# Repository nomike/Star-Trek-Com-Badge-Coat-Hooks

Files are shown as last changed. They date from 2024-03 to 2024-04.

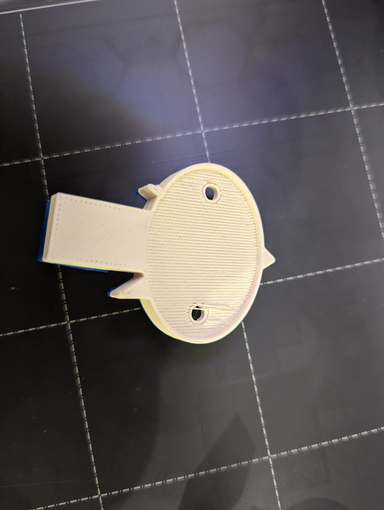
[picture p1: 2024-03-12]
photos/backside.png

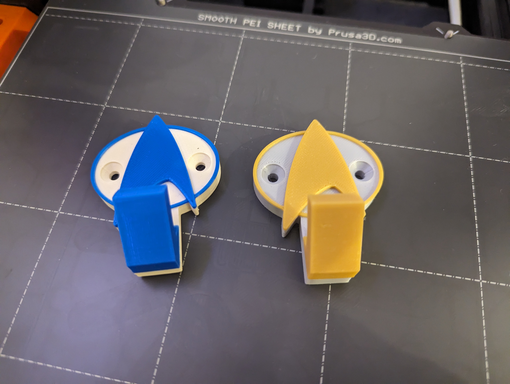
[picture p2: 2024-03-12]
photos/hooks.png

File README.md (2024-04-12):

Coat hooks featuring a Star Trek communicator badge. The hooks are designed to be mounted to a wall and are perfect for hanging coats, hats, or anything else you can think of.

#### Acknowledgements

Uses the follwing projects:

* <https://github.com/lar3ry/OpenSCAD---Move-STL-to-origin/tree/master> - To move the imported STL to the origin.
* <https://www.thingiverse.com/thing:1731893> - An OpenSCAD library for creating screw holes
* <https://worldvectorlogo.com/logo/starfleet> - for the Starfleet logo - Original design most likely owned by CBS - Edited with Inkscape into `star_fleet.svg`.
* <https://www.thingiverse.com/thing:49> - Coat Hook

#### Design

The back of the hook is hollowed out to account for uneven walls or dowels wich are not completely flush. This requires supports, but as they are attached to an invisible part of the hook, they don't influence the final appearance at all.

#### Colors

As you can see, introducing a filament change at the right layer provides for a very nice visual effect.

#### Knob

If you change the parameter `type` to `knob` you can print a knob instead of a hook. This is useful if you want to use the badge as a drawer knob or something similar. I haven't printed this version yet though.

#### Thingiverse

<https://www.thingiverse.com/thing:6528411>

#### GitHub

<https://github.com/nomike/star-trek-com-badge-coat-hook-and-door-knob>

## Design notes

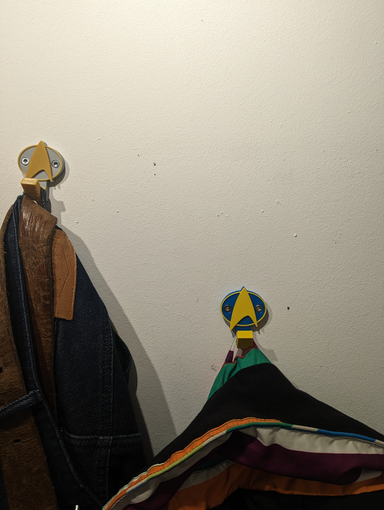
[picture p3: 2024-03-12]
photos/mounted.png

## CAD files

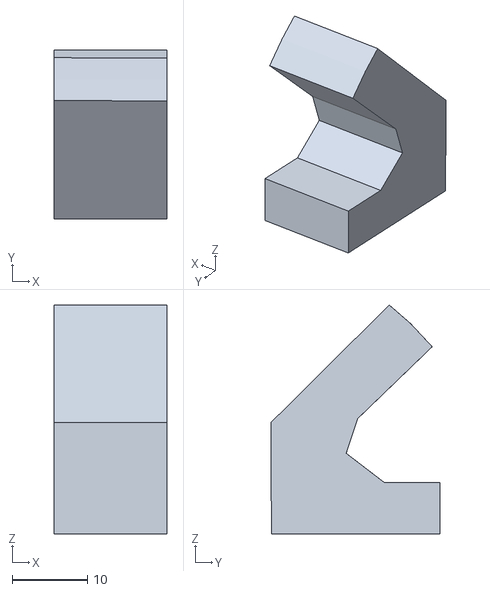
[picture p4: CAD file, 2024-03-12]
hook.stl
15.0 x 22.5 x 30.4

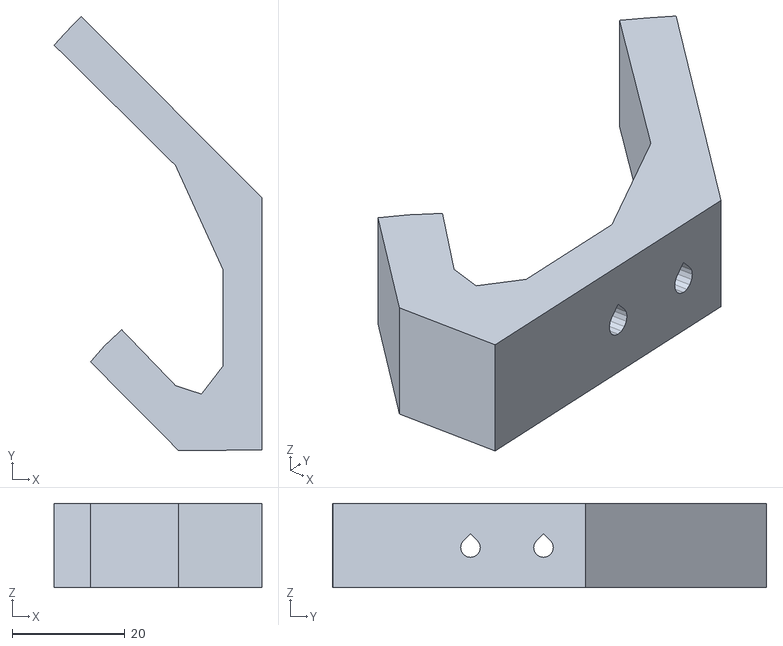
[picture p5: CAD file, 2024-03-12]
Coat-hook.stl
36.9 x 77.1 x 15.0

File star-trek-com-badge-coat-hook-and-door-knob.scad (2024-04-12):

/*
Star Trek Com Badge Coat Hooks

Copyright 2024 nomike[AT]nomike[DOT]com

Redistribution and use in source and binary forms, with or without
modification, are permitted provided that the following conditions are met:

1. Redistributions of source code must retain the above copyright notice, this
list of conditions and the following disclaimer.

2. Redistributions in binary form must reproduce the above copyright notice,
this list of conditions and the following disclaimer in the documentation
and/or other materials provided with the distribution.

THIS SOFTWARE IS PROVIDED BY THE COPYRIGHT HOLDERS AND CONTRIBUTORS “AS IS” AND
ANY EXPRESS OR IMPLIED WARRANTIES, INCLUDING, BUT NOT LIMITED TO, THE IMPLIED
WARRANTIES OF MERCHANTABILITY AND FITNESS FOR A PARTICULAR PURPOSE ARE
DISCLAIMED. IN NO EVENT SHALL THE COPYRIGHT HOLDER OR CONTRIBUTORS BE LIABLE FOR
ANY DIRECT, INDIRECT, INCIDENTAL, SPECIAL, EXEMPLARY, OR CONSEQUENTIAL DAMAGES
(INCLUDING, BUT NOT LIMITED TO, PROCUREMENT OF SUBSTITUTE GOODS OR SERVICES;
LOSS OF USE, DATA, OR PROFITS; OR BUSINESS INTERRUPTION) HOWEVER CAUSED AND ON
ANY THEORY OF LIABILITY, WHETHER IN CONTRACT, STRICT LIABILITY, OR TORT
(INCLUDING NEGLIGENCE OR OTHERWISE) ARISING IN ANY WAY OUT OF THE USE OF THIS
SOFTWARE, EVEN IF ADVISED OF THE POSSIBILITY OF SUCH DAMAGE.
*/

include <openscad-screw-holes/screw_holes.scad>;

$fn = 255;

oval_height = 7;
oval_radius = 18;
oval_scale_x = 1.3;
oval_scale_y = 1;
oval_brim_height = 1;
oval_brim_width = 1;

starfleet_emblem_svg_x = 105.058;
starfleet_emblem_svg_y = 167.008;
starfleet_width_percentage = 0.6;

_oval_width = oval_radius * 2 * oval_scale_x;
_oval_height = oval_radius * 2 * oval_scale_y;

starfleet_emblem_scale = (_oval_width * starfleet_width_percentage) / starfleet_emblem_svg_x;
_starfleet_emblem_width = starfleet_emblem_svg_x * starfleet_emblem_scale;
_startfleet_emblem_height = starfleet_emblem_svg_y * starfleet_emblem_scale;
starfleet_emblem_offset_x = (_oval_width / 2) - (_starfleet_emblem_width / 2);
starfleet_emblem_offset_y = (_oval_height / 2) - (_startfleet_emblem_height / 2);
starfleet_emblem_height = 9;
starfleet_emblem_brim_height = 1;
starfleet_emblem_brim_scale = 0.9;


hook_width = 15.013;
hook_offset_y = -21;

screw_m = M4;
screw_radius = 3;
screwhead_radius = 8;
screwhead_height = 5;
screw_center_offset_x = 16;
screw_center_offset_y = 0;

dowel_recess = 2;

knob_diameter = 10;
knob_height = 15;

type = "hook"; // "knob" or "hook"


// You should not need to change anything below here

// File: hook.stl
// X size: 15.013
// Y size: 22.512
// Z size: 30.432
// X position: 10.934
// Y position: -0.002
// Z position: 7.5
NE=1; NW=2; SW=3; SE=4; CTR=5;
module hook (where) {
	if (where == NE) {
		objNE ();
	}

	if (where == NW) {
		translate([ -15.013 , 0 , 0 ])
		objNE ();
	}

	if (where == SW) {
		translate([ -15.013 , -22.512 , 0 ])
		objNE ();
	}

	if (where == SE) {
		translate([ 0 , -22.512 , 0 , ])
		objNE ();
	}

	if (where == CTR) {
	translate([ -7.506 , -11.256 , -15.216 ])
		objNE ();
	}
}

module objNE () {
	translate([ -10.934 , 0.002 , -7.5 ])
		import("hook.stl");
}

difference() {
	union() {
		scale([oval_scale_x, oval_scale_y, 1]) translate([oval_radius, oval_radius, 0]) difference() {
			color("green") cylinder(h=oval_height + oval_brim_height, r=oval_radius);
			translate([0, 0, oval_height]) color("purple") cylinder(h=oval_brim_height, r=oval_radius - oval_brim_width);
		}
		translate([starfleet_emblem_offset_x, starfleet_emblem_offset_y, 0]) scale([starfleet_emblem_scale, starfleet_emblem_scale, 1]) union() {
			color("blue") linear_extrude(height=starfleet_emblem_height) import("star_fleet.svg");
		}
		if(type == "hook") {
			translate([(oval_radius * oval_scale_x) - (hook_width / 2), hook_offset_y, 0]) hook(NE);
		}
		if(type == "knob") {
			translate([(oval_radius * oval_scale_x), oval_radius , 0 - knob_height]) difference() {
				color("purple") cylinder(h=knob_height, d=knob_diameter);
				color("red") cylinder(h=knob_height, d=2.9);;

			}
		}
	}
	if(type == "hook") {
		translate([oval_radius * oval_scale_x - screw_center_offset_x, oval_radius * oval_scale_y + screw_center_offset_y, oval_height]) union() {
			rotate([0, 180, 0]) screw_hole(iso=ISO14581, m=screw_m, L=oval_height, b=0);
		}
		translate([oval_radius * oval_scale_x + screw_center_offset_x, oval_radius * oval_scale_y + screw_center_offset_y, oval_height]) union() {
			rotate([0, 180, 0]) screw_hole(iso=ISO14581, m=screw_m, L=oval_height, b=0);
		}
		scale([oval_scale_x, oval_scale_y, 1]) translate([oval_radius, oval_radius, 0]) difference() {
			translate([0, 0, 0]) color("purple") cylinder(h=dowel_recess, r=oval_radius - oval_brim_width);
		}
	}
}

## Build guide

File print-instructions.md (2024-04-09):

I printed the hooks with 50% cubic infill and used PLA as a material. One of the hooks gave in to the wait of two heavy jackets and a pair of quite heavy jeans. I then reprinted it with 90% cubic infill and cranked up the nozzle temperature to 240°C for the first and 230°C for subsequent layers.

I also changed the cooling options in PrusaSlicer to improve layer adhesion:

Fan speed min: 50%
Enable dynamic fan speeds: true
speed for 0% overlap (bridge): 50%
speed for 25% overlap: 70%
speed for 50% overlap: 80%
speed for 75% overlap: 100%

Adding more perimters would have made the hook even more sturdy I think, but mine has held up for a few weeks now with no issues, so I had no reason to reprint it.

Also it was only one hook which failed so far, the others are fine, even with the lower infill and cooling settings.

Organic supports work great on this one.

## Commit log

2024-03-12 Initial commit.
    [Coat-hook.stl, hook.stl, screw_holes.scad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]
2024-04-09 Remove hack from star-trek-coat-hook.scad as it is no longer needed.
    [star-trek-coat-hook.scad]
2024-04-09 Switch to BSD-2-Clause license.
    [star-trek-coat-hook.scad]
2024-04-09 Add print instructions.
2024-04-12 Rename files to be more consistent.
    [star-trek-com-badge-coat-hook-and-door-knob.scad]
2024-04-12 Import openscad-screw-holes library from GitHub as a submodule.
    [screw_holes.scad, star-trek-com-badge-coat-hook-and-door-knob.scad]
